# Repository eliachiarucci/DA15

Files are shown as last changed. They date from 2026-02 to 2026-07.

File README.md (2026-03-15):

# DA15 - USB Audio DAC + Amplifier

The goal of this project was to create a minimal amplifier for desktop use, using only a single USB-C cable for both data and power.
The amp outputs a max of 4.4W into 4Ω per channel, which is often enough for a good listening experience in a small room with moderately sensitive speakers.
I personally keep the volume at 30% most of the time.

The amp is also quite portable, and can be easily powered with a phone through a USB-C cable.

## Main components:

- **MCU**: STM32H503
- **DAC**: PCM5102A
- **AMP**: PAM8965

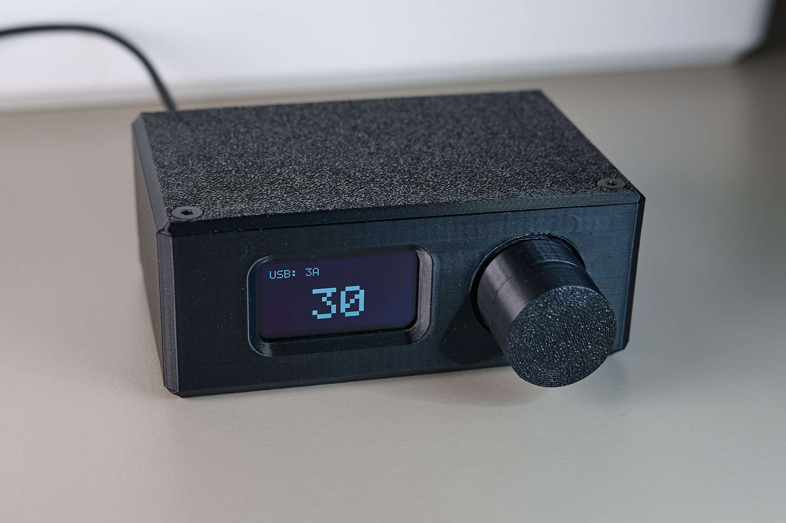
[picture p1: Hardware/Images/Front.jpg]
DA15 Front

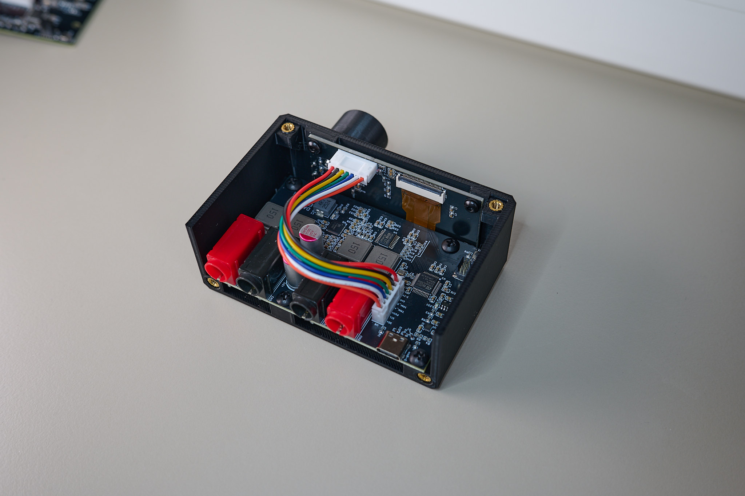
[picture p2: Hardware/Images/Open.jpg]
DA15 Top

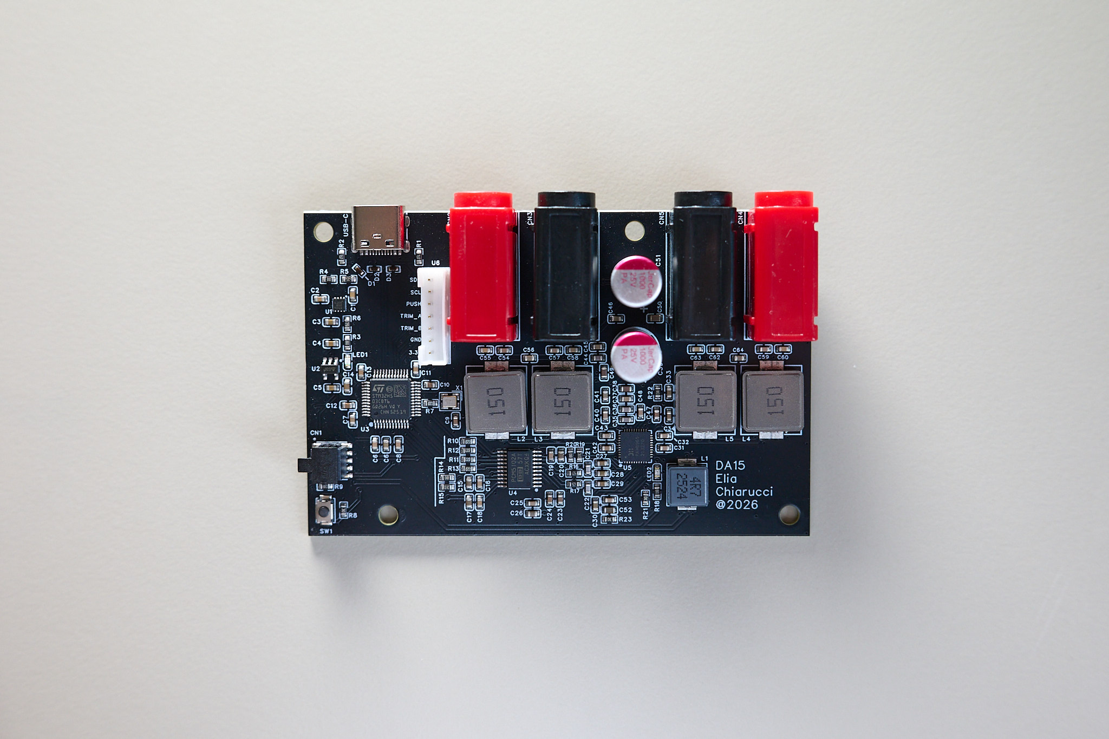
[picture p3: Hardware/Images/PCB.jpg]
DA15 PCB


For additional pictures, see [Hardware/Images](Hardware/Images/).

## Features

- **Single USB-C cable**: for both power and audio (USB Audio Class 1, 24-bit/48kHz).
- **Power** - 2 x 4.4W into 4Ω and 2 x 2.2W into 8Ω speakers (@ 0.035% THD). Can be set at max volume without losing quality.
- **USB Audio Class 1** - 24-bit/48kHz stereo with dedicated 24.576mhz audio crystal.
- **EQ** - Basic 2 bass and treble EQ or advanced EQ profiles via the [EQOS app](https://github.com/eliachiarucci/EQOS).
- **USB-C power detection** - adapts output level based on CC line voltage (500mA / 1.5A / 3A).
- **OLED UI** - SH1106 128x64 display with rotary encoder navigation.
- **DFU firmware update** - update over USB.
- **Persistent user settings** - stored in flash with wear leveling.
- **Low power consumption** - 0.5W in standby.

## Building

**Requirements:** CMake 3.22+, Ninja, ARM GCC toolchain

The [STM32 VS Code Extension](https://marketplace.visualstudio.com/items?itemName=stmicroelectronics.stm32-vscode-extension) is recommended for development.

```bash
cmake --preset Release
cmake --build build/Release
```

Or clicking the "Build" button on the bottom of VSCode.

## Debugging

There are 2 debugging profiles (in the Run and Debug tab):
**STM32Cube: STM32 Launch ST-Link GDB Server**
This is the profile created by the STM32 Extension, it will use ST-Link to flash the board.

**Debug with OpenOCD**
This profile will use OpenOCD to flash the board, and will also spawn an RTT terminal with logging directly in VSCode.

## Flashing

> **Note:** Upstream OpenOCD does not support the STM32H5 family. You need the [ST fork of OpenOCD](https://github.com/STMicroelectronics/OpenOCD) for debugging and flashing via ST-Link.
> See below for [macOS install instructions](#installing-st-openocd-for-stm32h5-support-macos).

**With ST-Link:**
```bash
openocd -f interface/stlink.cfg -f target/stm32h5x.cfg \
  -c "program build/Release/DA15.elf verify reset exit"
```

**Over USB (DFU):**
Enter DFU mode from the device menu or run `dfu-util --detach`, then:
```bash
dfu-util -a 0 -s 0x08000000:leave -D build/Release/DA15.bin
```

STM32CubeProgrammer can also be used for both ST-Link and USB DFU flashing.

## Project Structure

```
App/           Application firmware
├── Inc/       Headers
└── Src/       Implementation (audio pipeline, EQ, display, USB, settings)
Core/          STM32CubeMX generated HAL init code
Drivers/       STM32H5xx HAL library
Lib/           TinyUSB (USB stack), SEGGER RTT (debug)
```

## Installing ST OpenOCD for STM32H5 support (macOS)

```bash
# Install dependencies (if not already installed)
brew install automake autoconf libtool pkg-config libusb texinfo

# Unlink upstream OpenOCD if installed
brew unlink open-ocd 2>/dev/null

# Clone and build
git clone https://github.com/STMicroelectronics/OpenOCD.git
cd /tmp/st-openocd
./bootstrap
./configure --enable-stlink CFLAGS="-Wno-gnu-folding-constant"
make -j$(sysctl -n hw.ncpu)

# Install
sudo mkdir -p /opt/homebrew/bin /opt/homebrew/share/openocd/scripts
sudo cp src/openocd /opt/homebrew/bin/openocd
sudo cp -r tcl/* /opt/homebrew/share/openocd/scripts/

## Dependencies

| Library | License | Purpose |
|---------|---------|---------|
| [TinyUSB](https://github.com/hathach/tinyusb) | MIT | USB Audio Class 1 stack |
| [STM32H5 HAL](https://github.com/STMicroelectronics/stm32h5xx-hal-driver) | BSD-3-Clause | Hardware abstraction |
| [SEGGER RTT](https://www.segger.com/products/debug-probes/j-link/technology/about-real-time-transfer/) | BSD-1-Clause | Debug output (optional) |

## Licenses

The software of this project is licensed under the [GPL-3.0-only](LICENSE).

All the hardware files are licensed under the [CERN-OHL-S-2.0](Hardware/LICENSE).

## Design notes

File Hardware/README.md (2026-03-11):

# Hardware files for DA15.

This project was made using EasyEDA Pro (free software).

The screen and encoder PCB are part of another project that will be soon published in another repo.
However, any SH1106 screen and encoder can be used, as long as their PCB thickness is 1.6mm.

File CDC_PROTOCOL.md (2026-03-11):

# DA15 USB CDC Protocol — External App Integration Guide

## Connection

The DA15 enumerates as a USB composite device with three interfaces:
- **Audio** (UAC1 stereo speaker, 48kHz/24-bit)
- **DFU Runtime** (firmware update trigger)
- **CDC** (virtual serial port for EQ profile management)

The CDC interface has string descriptor **"DA15 EQ Config"**. Use this to identify the correct serial port.

**USB identifiers:** VID `0x1209`, PID `0xDA15`

No baud rate configuration is needed (it's USB CDC, not a real UART), but most serial libraries require one — any value works (e.g. 115200).

## Binary Frame Protocol

All communication is request/response. The host (app) sends a request, the device always replies.

### Request frame
```
[CMD:1] [LEN:2 LE] [PAYLOAD:LEN bytes] [CRC8:1]
```

### Response frame
```
[CMD|0x80:1] [LEN:2 LE] [STATUS:1] [PAYLOAD:LEN-1 bytes] [CRC8:1]
```

- **CMD**: Command byte. Response echoes it with bit 7 set (`CMD | 0x80`).
- **LEN**: Little-endian uint16. In requests, this is the payload size. In responses, this is `1 + payload_size` (the status byte counts toward the length).
- **CRC8**: Polynomial `0x07` (SMBus), initial value `0x00`. Computed over everything before the CRC byte (header + payload, or header + status + payload).

### CRC8 Implementation

```javascript
function crc8(data) {
  let crc = 0x00;
  for (const byte of data) {
    crc ^= byte;
    for (let bit = 0; bit < 8; bit++) {
      if (crc & 0x80) crc = ((crc << 1) ^ 0x07) & 0xFF;
      else crc = (crc << 1) & 0xFF;
    }
  }
  return crc;
}
```

### Status Codes

| Value | Name | Meaning |
|---|---|---|
| `0x00` | OK | Success |
| `0x01` | ERR_INVALID_CMD | Unknown command byte |
| `0x02` | ERR_INVALID_PARAM | Bad ID, wrong payload size, etc. |
| `0x03` | ERR_FLASH | Flash erase/write failed |

## Commands

### 0x01 — GET_DEVICE_INFO

**Request payload:** (none, LEN=0)

**Response payload (9 bytes):**
| Offset | Type | Field |
|---|---|---|
| 0 | uint8 | hw_model (1=DA15) |
| 1 | uint8 | hw_version_major |
| 2 | uint8 | hw_version_minor |
| 3 | uint8 | fw_version_major |
| 4 | uint8 | fw_version_minor |
| 5 | uint8 | fw_version_patch |
| 6 | uint8 | max_profiles (10) |
| 7 | uint8 | max_filters_per_profile (10) |
| 8 | uint8 | active_profile_id (0-9, or 0xFF=OFF) |

**hw_model values:**
| Value | Model |
|---|---|
| 1 | DA15 |
| 2 | HA1 |

### 0x02 — GET_PROFILE_LIST

**Request payload:** (none, LEN=0)

**Response payload (variable):**
| Offset | Type | Field |
|---|---|---|
| 0 | uint8 | count (number of stored profiles) |
| 1+ | repeated | For each profile: `[id:1] [name:16]` |

Each entry is 17 bytes: 1 byte slot ID (0-9) + 16 bytes null-terminated name. Only non-empty slots are included.

### 0x03 — GET_ACTIVE

**Request payload:** (none, LEN=0)

**Response payload (1 byte):** `[active_profile_id:1]` (0-9 for a profile, `0xFF` for OFF).

### 0x04 — GET_PROFILE

**Request payload (1 byte):** `[profile_id:1]`

**Response payload (380 bytes):** Raw `eq_profile_t` struct bytes (see data structures below).

Returns `ERR_INVALID_PARAM` if the slot is empty or ID >= 10.

### 0x05 — SET_PROFILE

**Request payload (381 bytes):** `[profile_id:1] [eq_profile_t:380]`

Writes a profile to the specified slot **in RAM only**. Call `SAVE_TO_FLASH` afterward to persist. Returns `ERR_INVALID_PARAM` if ID >= 10.

### 0x06 — DELETE_PROFILE

**Request payload (1 byte):** `[profile_id:1]`

Clears the profile slot **in RAM only**. Call `SAVE_TO_FLASH` to persist. If the deleted profile was active, the device switches to OFF. Returns `ERR_INVALID_PARAM` if ID >= 10.

### 0x07 — SET_ACTIVE

**Request payload (1 byte):** `[profile_id:1]` (0-9 for a profile, `0xFF` for OFF)

Takes effect immediately — the device switches EQ processing to the selected profile (or back to legacy bass/treble if OFF). The active profile is also persisted in the device's settings sector automatically.

### 0x08 — SAVE_TO_FLASH

**Request payload:** (none, LEN=0)

Erases the profile flash sector and writes all current profiles from RAM. Returns `ERR_FLASH` if the operation fails.

### 0x80 — GET_MANUFACTURER

**Request payload:** (none, LEN=0)

**Response payload (variable):** Current manufacturer string as raw ASCII (no null terminator).

### 0x81 — GET_PRODUCT

**Request payload:** (none, LEN=0)

**Response payload (variable):** Current product string as raw ASCII (no null terminator).

### 0x82 — GET_AUDIO_ITF

**Request payload:** (none, LEN=0)

**Response payload (variable):** Current audio interface string as raw ASCII (no null terminator).

### 0x85 — SET_MANUFACTURER

**Request payload (1–32 bytes):** Raw ASCII string (no null terminator required).

Overrides the USB manufacturer string descriptor **in RAM only**. Takes effect on the next descriptor request from the host (requires re-enumeration to be visible to the OS). Call `REBOOT` to persist all string changes to flash. Returns `ERR_INVALID_PARAM` if the payload is empty or longer than 32 bytes.

### 0x86 — SET_PRODUCT

**Request payload (1–32 bytes):** Raw ASCII string (no null terminator required).

Overrides the USB product string descriptor **in RAM only**. Same re-enumeration caveat as `SET_MANUFACTURER`. Call `REBOOT` to persist all string changes to flash. Returns `ERR_INVALID_PARAM` if the payload is empty or longer than 32 bytes.

### 0x87 — SET_AUDIO_ITF

**Request payload (1–32 bytes):** Raw ASCII string (no null terminator required).

Overrides the USB audio interface string descriptor **in RAM only**. Same re-enumeration caveat as `SET_MANUFACTURER`. Call `REBOOT` to persist all string changes to flash. Returns `ERR_INVALID_PARAM` if the payload is empty or longer than 32 bytes.

### 0x90 — ENTER_DFU

**Request payload:** (none, LEN=0)

Sends an OK response, then reboots the device into the STM32 system bootloader (DFU mode). The device re-enumerates as a DFU device for firmware flashing via `dfu-util`.

### 0x91 — GET_DFU_SERIAL

**Request payload:** (none, LEN=0)

**Response payload (12 bytes):** The DFU bootloader serial as 12 uppercase ASCII hex characters, derived from the 96-bit UID: 8 hex digits of `(UID0 + UID2)` followed by 4 hex digits of `(UID1 >> 16)`. Can be passed to `dfu-util -S <serial>` to target a specific device.

### 0x92 — REBOOT

**Request payload:** (none, LEN=0)

Persists any pending USB string descriptor changes (manufacturer, product, audio interface) to flash, then sends an OK response and performs a clean system reset via `NVIC_SystemReset()`. The device re-enumerates normally. Returns `ERR_FLASH` if the flash write fails (no reboot occurs).

### 0x93 — GET_DAC

**Request payload:** (none, LEN=0)

**Response payload (1 byte):** `0x00` = DAC muted (off), `0x01` = DAC unmuted (on).

### 0x94 — GET_AMP

**Request payload:** (none, LEN=0)

**Response payload (1 byte):** `0x00` = amplifier disabled (off), `0x01` = amplifier enabled (on).

### 0x95 — SET_DAC

**Request payload (1 byte):** `[enable:1]` — `0x00` = off (mute DAC), `0x01` = on (unmute DAC).

Directly controls the DAC mute GPIO. Returns `ERR_INVALID_PARAM` if the value is not 0 or 1.

### 0x96 — SET_AMP

**Request payload (1 byte):** `[enable:1]` — `0x00` = off (disable amplifier), `0x01` = on (enable amplifier).

Directly controls the amplifier enable GPIO. Returns `ERR_INVALID_PARAM` if the value is not 0 or 1.

## Data Structures (Binary Layout)

### eq_filter_t — 36 bytes

All floats are IEEE 754 single-precision, **little-endian** (ARM native byte order).

| Offset | Size | Type | Field | Description |
|---|---|---|---|---|
| 0 | 4 | float | b0 | Biquad coefficient |
| 4 | 4 | float | b1 | Biquad coefficient |
| 8 | 4 | float | b2 | Biquad coefficient |
| 12 | 4 | float | a1 | Biquad coefficient |
| 16 | 4 | float | a2 | Biquad coefficient |
| 20 | 4 | float | freq | Center/corner frequency (Hz) |
| 24 | 4 | float | gain | Gain in dB |
| 28 | 4 | float | q | Q factor |
| 32 | 1 | uint8 | type | Filter type (see below) |
| 33 | 1 | uint8 | enabled | 0=bypass, 1=active |
| 34 | 2 | — | padding | Set to 0x00 |

**Filter types:**
| Value | Type |
|---|---|
| 0 | OFF (filter slot unused) |
| 1 | Bell (peaking EQ) |
| 2 | Low Shelf |
| 3 | High Shelf |
| 4 | Low Pass |
| 5 | High Pass |

### eq_profile_t — 380 bytes

| Offset | Size | Type | Field | Description |
|---|---|---|---|---|
| 0 | 16 | char[16] | name | Null-terminated UTF-8 string (max 15 chars + null) |
| 16 | 1 | uint8 | filter_count | Number of active filters (0-10) |
| 17 | 3 | — | padding | Set to 0x00 |
| 20 | 360 | eq_filter_t[10] | filters | Array of 10 filter slots |

Filters beyond `filter_count` are ignored by the device but should be zeroed.

## Biquad Coefficient Computation

The values must pre-compute biquad coefficients. The device uses **Direct Form II Transposed** processing:

```
y[n] = b0*x[n] + s1
s1   = b1*x[n] - a1*y[n] + s2
s2   = b2*x[n] - a2*y[n]
```

Coefficients must be **normalized** (a0 = 1, divide all by a0). The `a1` and `a2` values stored are the standard denominator coefficients — the firmware applies them with a **minus sign** as shown above.

Use the standard Audio EQ Cookbook formulas (Robert Bristow-Johnson). Sample rate is always **48000 Hz**.

## Typical Workflow

```
1. Open CDC serial port (identify by VID/PID or "DA15 EQ Config" descriptor)
2. GET_DEVICE_INFO → check firmware version, get current state
3. GET_PROFILE_LIST → display stored profiles
4. User creates/edits a profile in the UI
5. SET_PROFILE(id, data) → upload to device RAM
6. SET_ACTIVE(id) → switch to the new profile (immediate audio effect)
7. SAVE_TO_FLASH → persist all profiles
```

For bulk operations (uploading multiple profiles), send SET_PROFILE for each, then a single SAVE_TO_FLASH at the end.

## Example: Sending GET_DEVICE_INFO

```javascript
// Build request frame
const cmd = 0x01;
const len = 0; // no payload
const frame = Buffer.from([cmd, len & 0xFF, (len >> 8) & 0xFF]);
const crcByte = crc8(frame);
const packet = Buffer.concat([frame, Buffer.from([crcByte])]);
// packet = [0x01, 0x00, 0x00, 0x79]

// Send over serial port, then read response:
// [0x81, 0x0A, 0x00, 0x00, 0x01, 0x01, 0x00, 0x01, 0x00, 0x00, 0x0A, 0x0A, 0xFF, <crc>]
//  ^CMD|0x80   ^LEN=10      ^OK  ^hw1  ^v1.0       ^fw1.0.0          ^10   ^10   ^OFF
```

## Example: Uploading a Profile

```javascript
// Build a profile with one bell filter at 1kHz, +3dB, Q=1.4
const name = Buffer.alloc(16); // null-terminated
Buffer.from('My Profile').copy(name);

const filter = Buffer.alloc(36);
// Write biquad coefficients (pre-computed for 1kHz bell, +3dB, Q=1.4, fs=48000)
filter.writeFloatLE(1.0015, 0);   // b0
filter.writeFloatLE(-1.8955, 4);  // b1
filter.writeFloatLE(0.8985, 8);   // b2
filter.writeFloatLE(-1.8955, 12); // a1 (note: firmware negates these)
filter.writeFloatLE(0.9000, 16);  // a2
filter.writeFloatLE(1000.0, 20);  // freq
filter.writeFloatLE(3.0, 24);     // gain
filter.writeFloatLE(1.4, 28);     // q
filter[32] = 1;                   // type = FILTER_BELL
filter[33] = 1;                   // enabled

// Build eq_profile_t (380 bytes)
const profile = Buffer.alloc(380);
name.copy(profile, 0);            // name at offset 0
profile[16] = 1;                  // filter_count = 1
// padding at 17-19 is already 0
filter.copy(profile, 20);         // first filter at offset 20
// remaining 9 filter slots are already zeroed

// Build SET_PROFILE request: [cmd] [len_lo] [len_hi] [id] [profile...] [crc]
const id = 0; // slot 0
const payload = Buffer.concat([Buffer.from([id]), profile]); // 381 bytes
const header = Buffer.from([0x05, payload.length & 0xFF, (payload.length >> 8) & 0xFF]);
const fullFrame = Buffer.concat([header, payload]);
const crc = crc8(fullFrame);
const packet = Buffer.concat([fullFrame, Buffer.from([crc])]);

// Send packet, expect response: [0x85, 0x01, 0x00, 0x00, <crc>]
//                                 ^CMD   ^LEN=1     ^OK

// Then persist:
// SAVE_TO_FLASH: [0x08, 0x00, 0x00, <crc>]
```

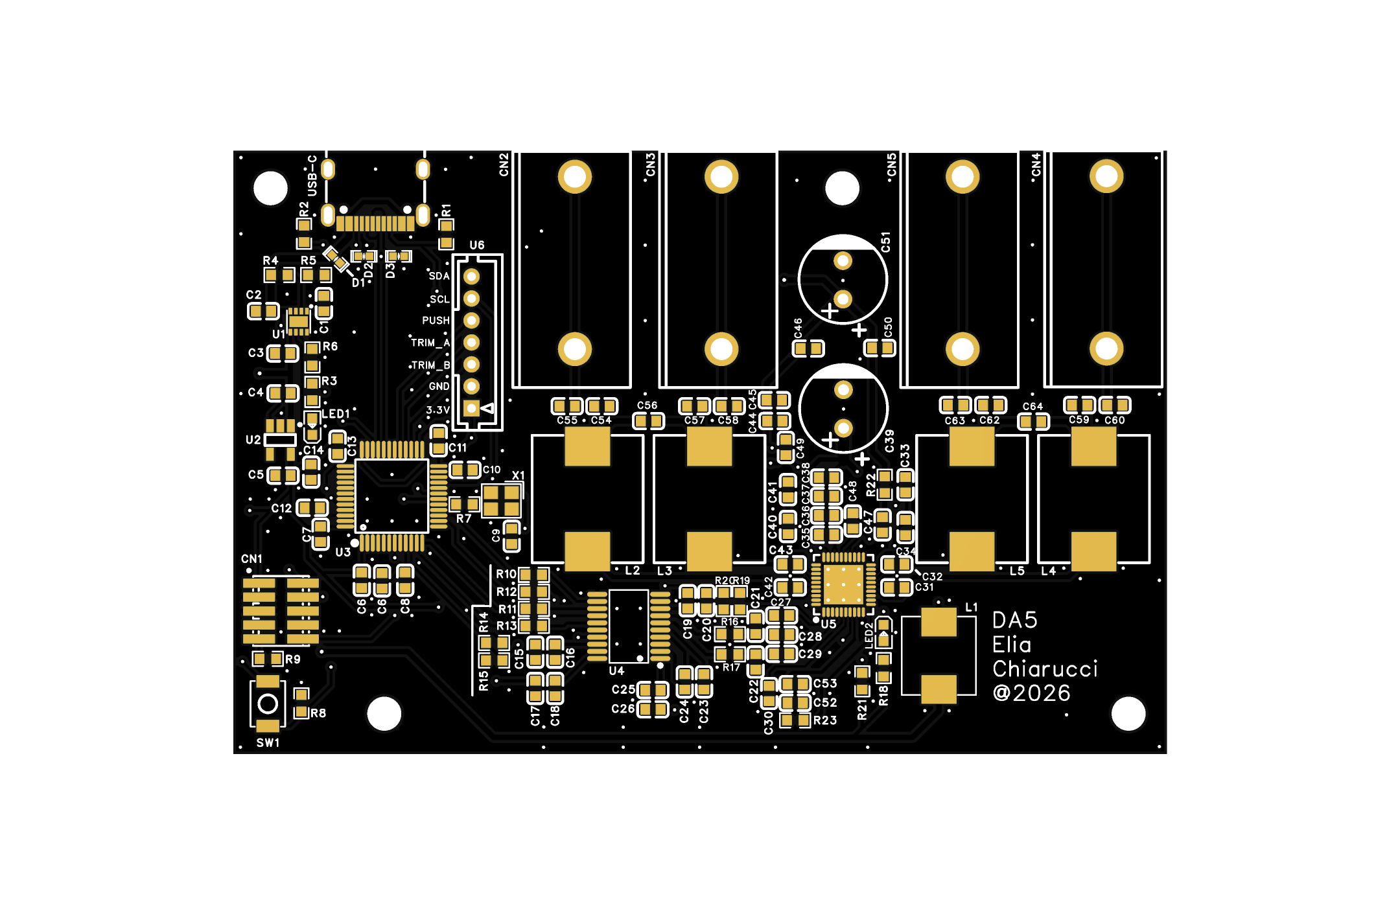
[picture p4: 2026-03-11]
Hardware/Images/2D_Render.png

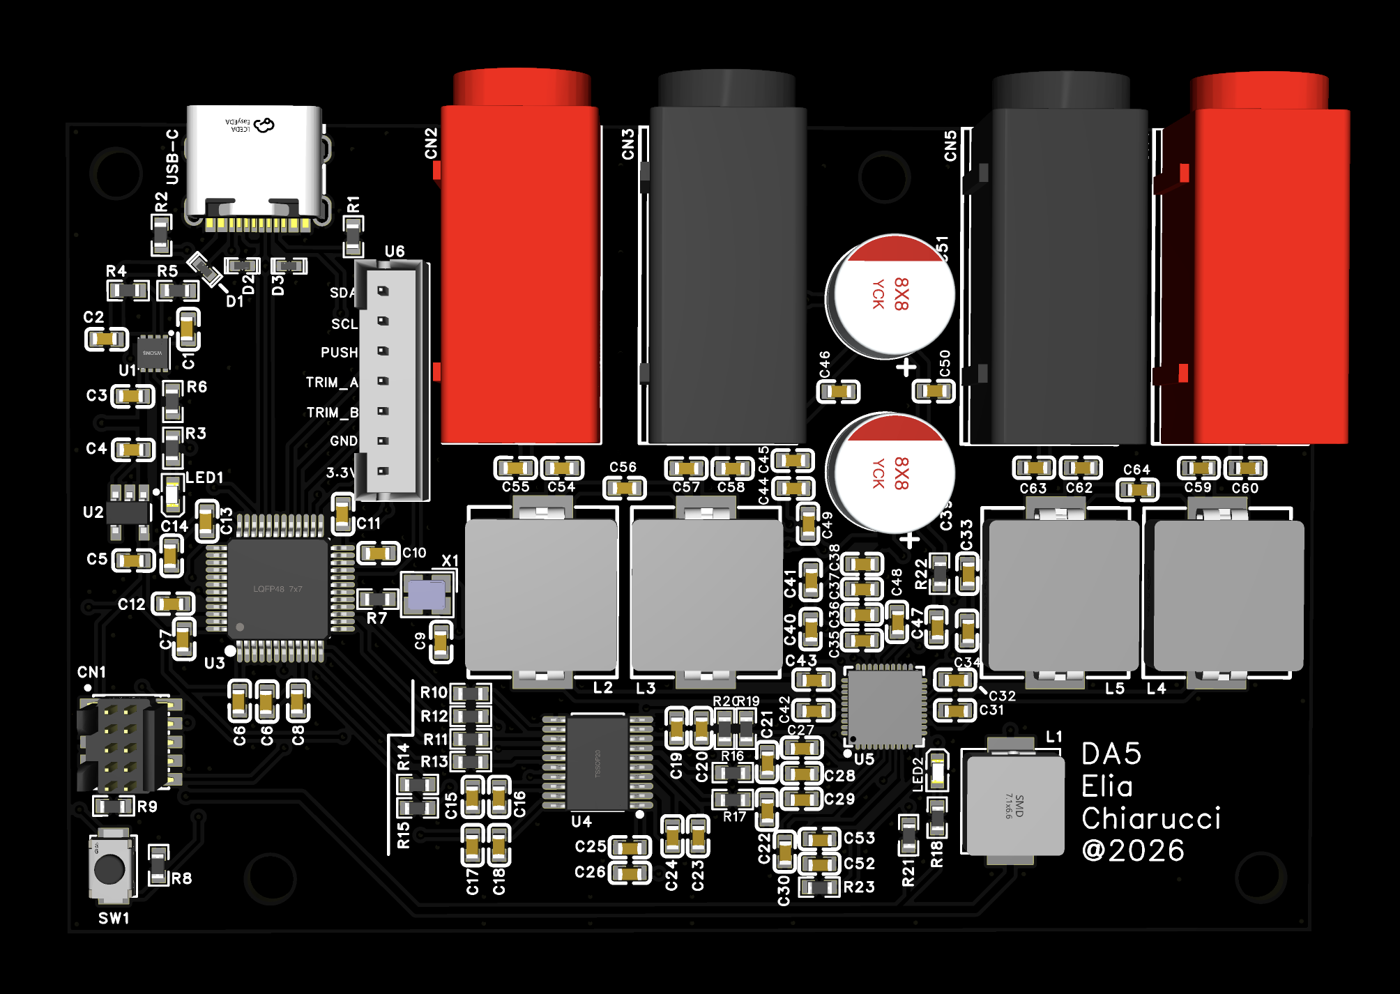
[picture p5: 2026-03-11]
Hardware/Images/3D_Render.png

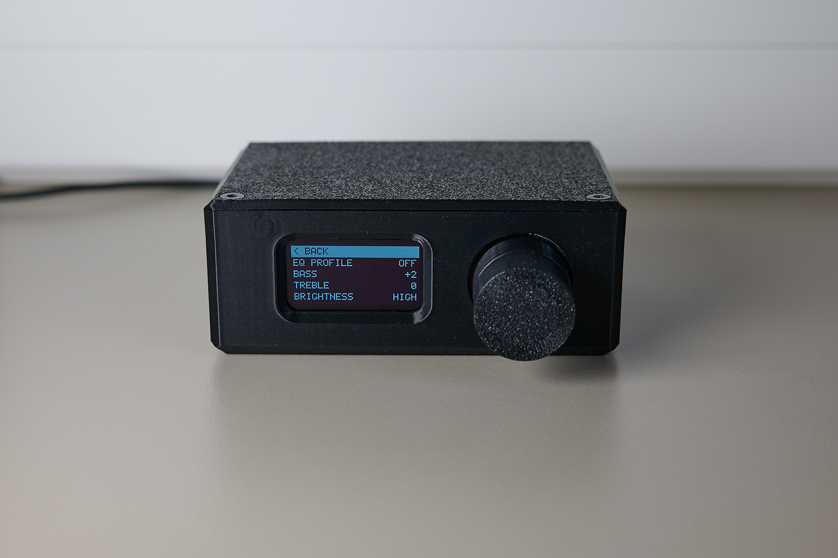
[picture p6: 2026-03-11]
Hardware/Images/Menu.jpg

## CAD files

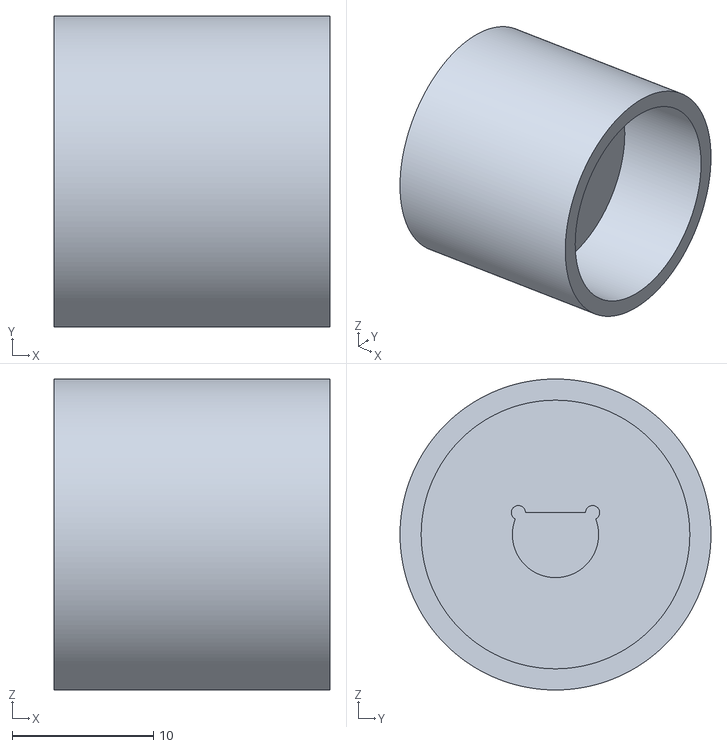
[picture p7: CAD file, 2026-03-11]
Hardware/Case/Knob.stl
19.5 x 22.0 x 22.0

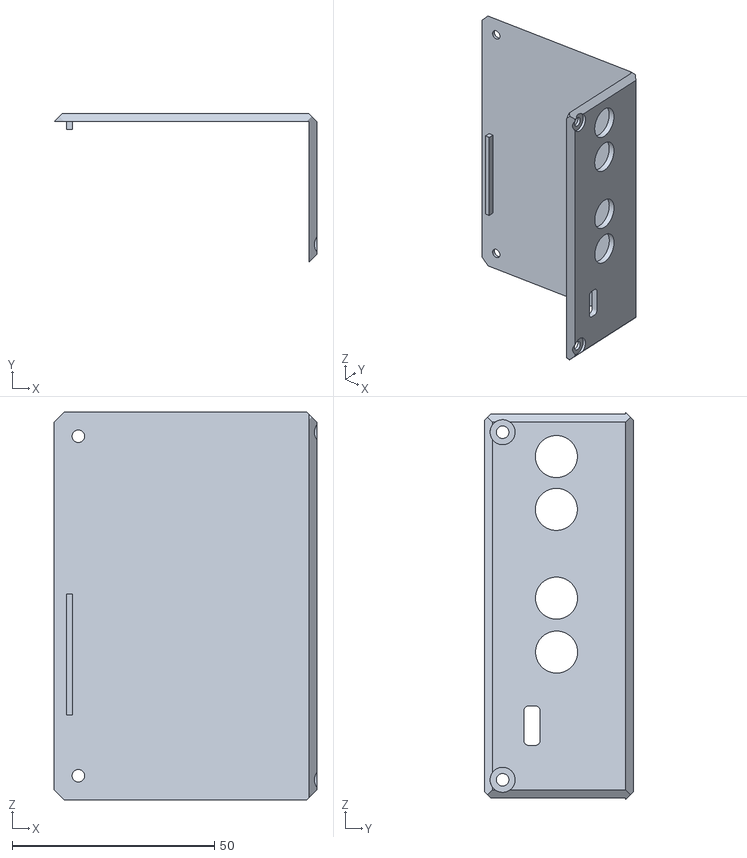
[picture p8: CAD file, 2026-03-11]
Hardware/Case/Top.stl
65.0 x 36.9 x 96.0

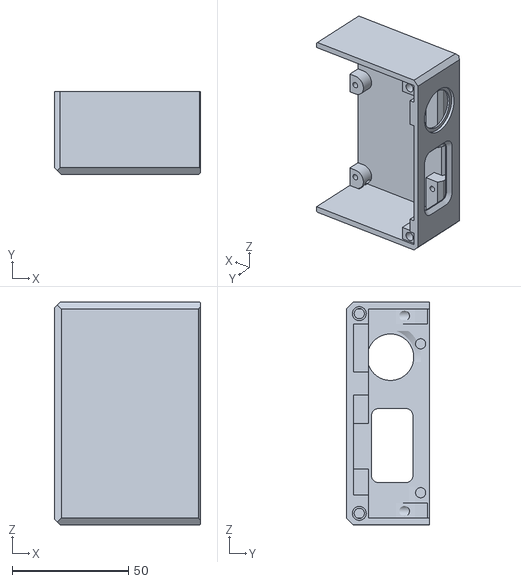
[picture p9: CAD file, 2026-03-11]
Hardware/Case/Base.stl
63.0 x 35.9 x 96.0

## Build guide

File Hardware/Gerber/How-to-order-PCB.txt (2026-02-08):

How to Order PCB

Please refer to:
https://prodocs.easyeda.com/en/pcb/order-order-pcb/index.html

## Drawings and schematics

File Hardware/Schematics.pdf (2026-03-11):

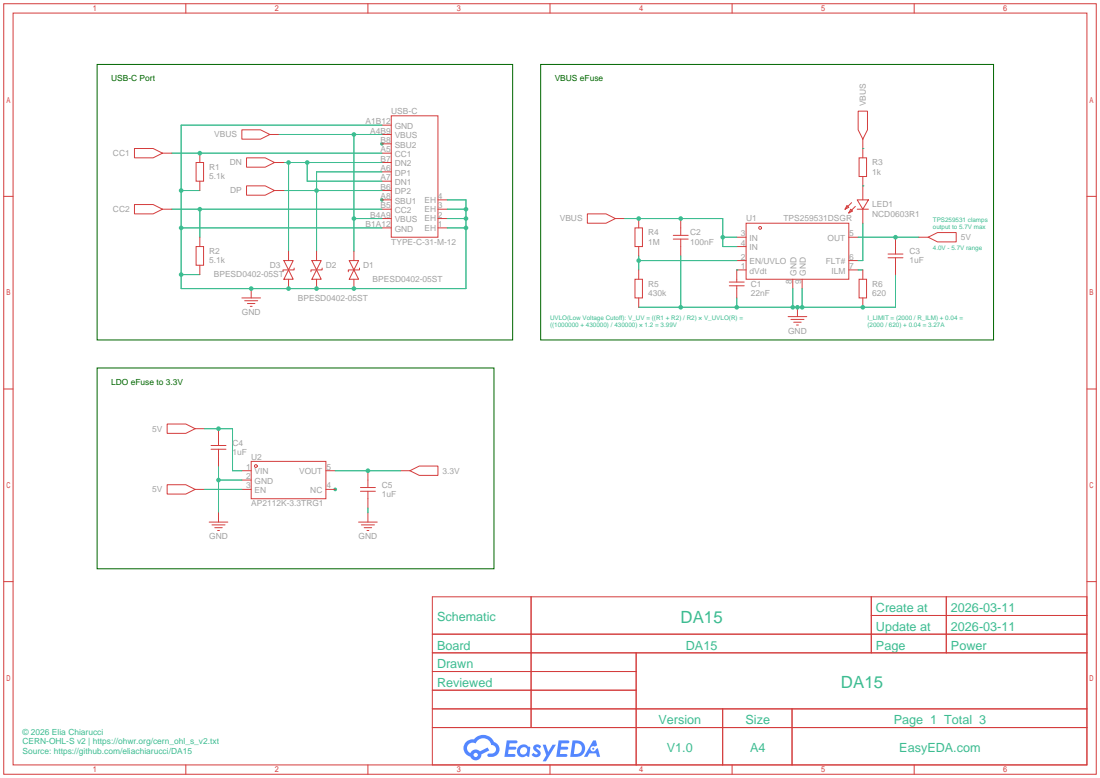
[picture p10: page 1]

UVLO(Low Voltage Cutoff): V_UV = ((R1 + R2) / R2) × V_UVLO(R) =

Schematic | DA15 | Create at | 2026-03-11

Update at | 2026-03-11

Board | DA15 | Page | Power
Drawn | | DA15
Reviewed

Version | Size | Page 1 Total 3
V1.0 | A4 | EasyEDA.com

© 2026 Elia Chiarucci
CERN-OHL-S v2 | https://ohwr.org/cern_ohl_s_v2.txt
Source: https://github.com/eliachiarucci/DA15

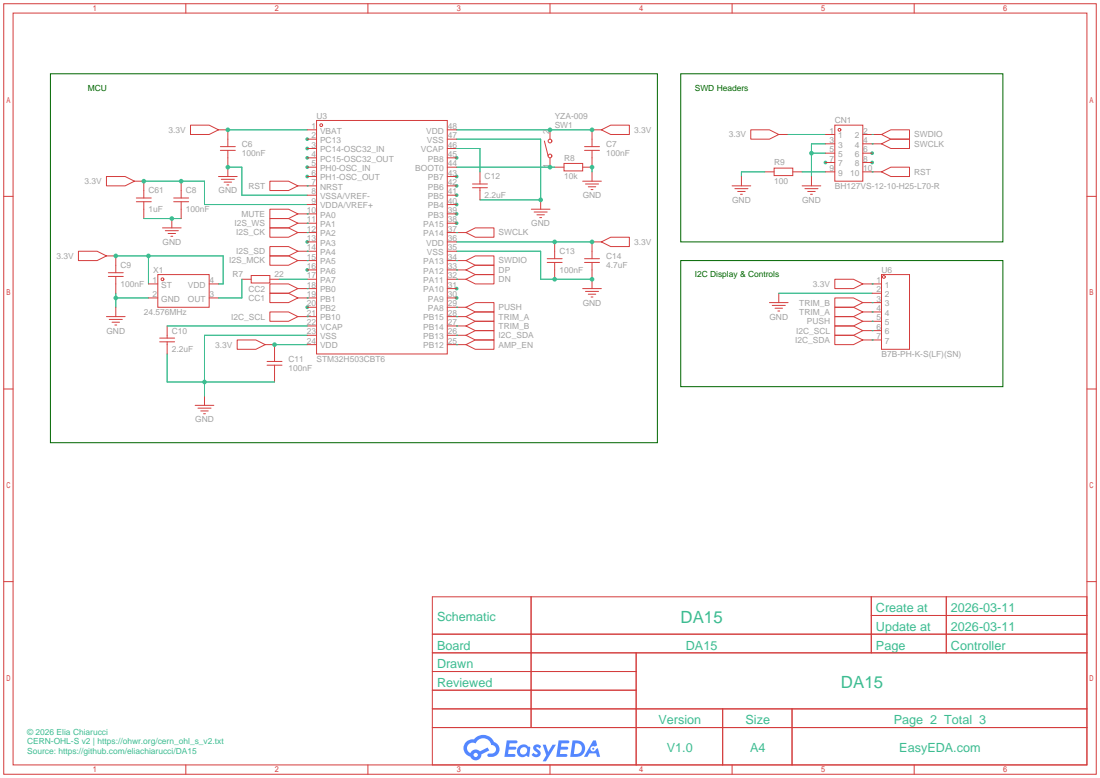
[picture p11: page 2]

Schematic | DA15 | Create at | 2026-03-11

Update at | 2026-03-11

Board | DA15 | Page | Controller
Drawn | | DA15
Reviewed

PGND 20 GAIN 21 PGND 22 PGND 23 SW 24 SW 25 BST 26 PVDD 27 PVDD 28 VBAT2 29 VBAT1 30 PGND 31 RFBN 32 ROUTN 33 RBSTN 34 RPVDD 35 RBSTP 36 ROUTP 37 RFBP 38 PGND 39 GND 40 EP 41

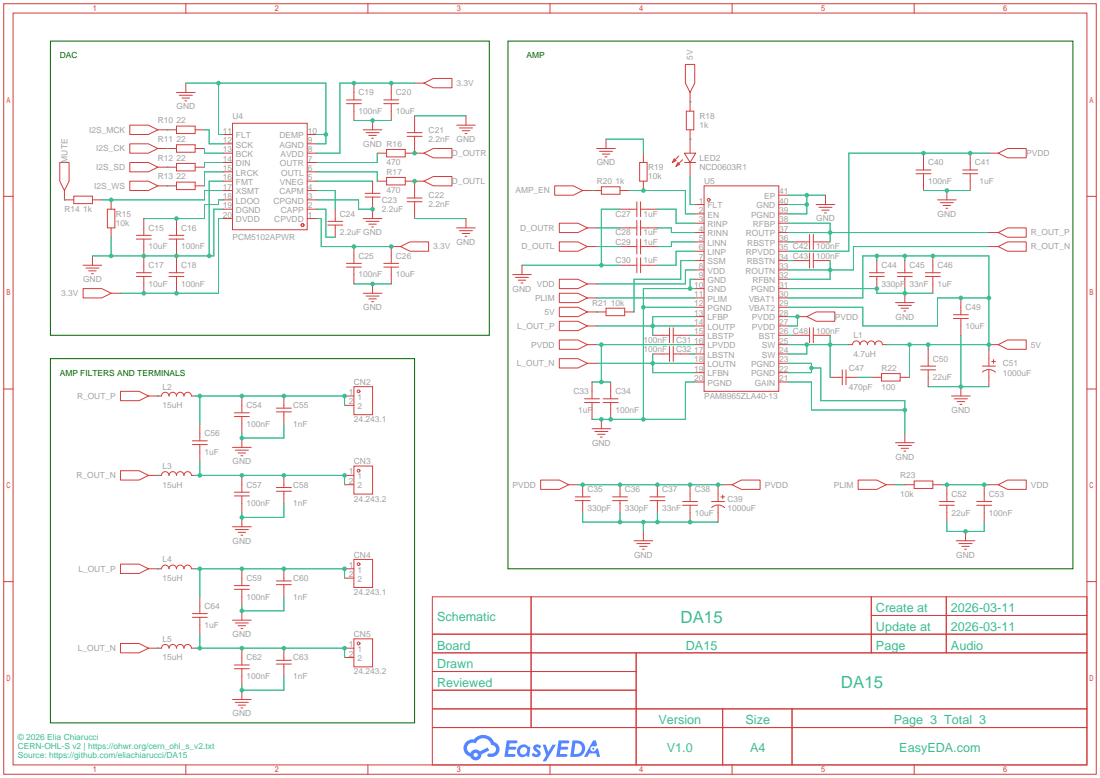
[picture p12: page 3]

AMP FILTERS AND TERMINALS

Schematic | DA15 | Create at | 2026-03-11

Update at | 2026-03-11

Board | DA15 | Page | Audio
Drawn | | DA15
Reviewed

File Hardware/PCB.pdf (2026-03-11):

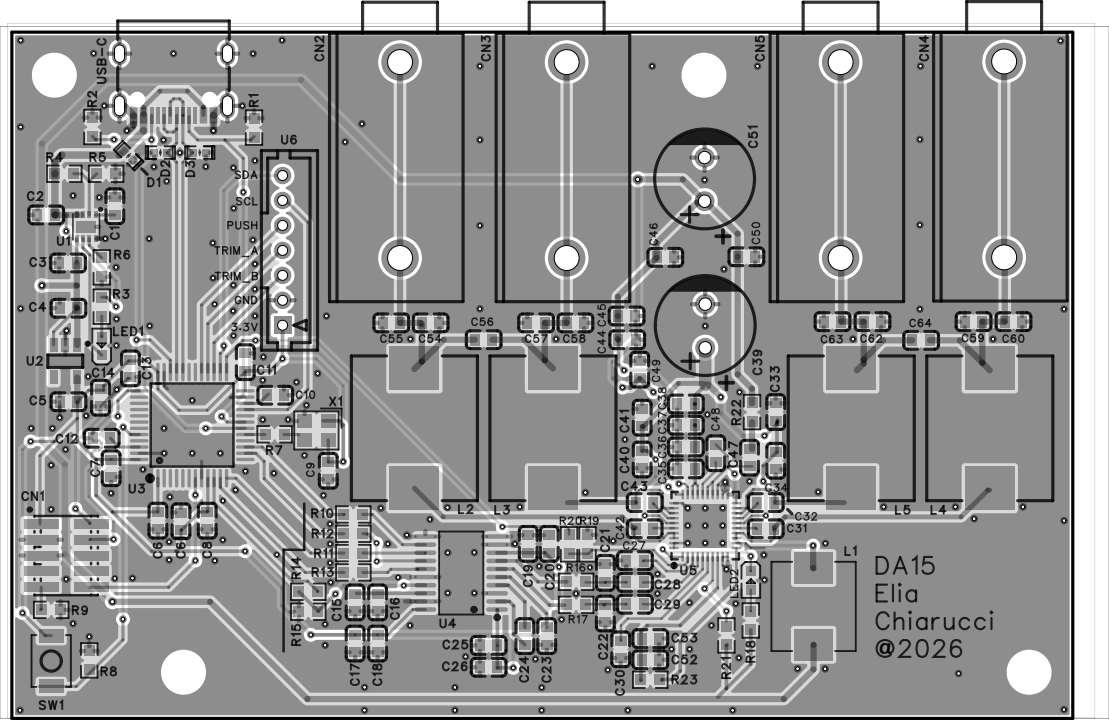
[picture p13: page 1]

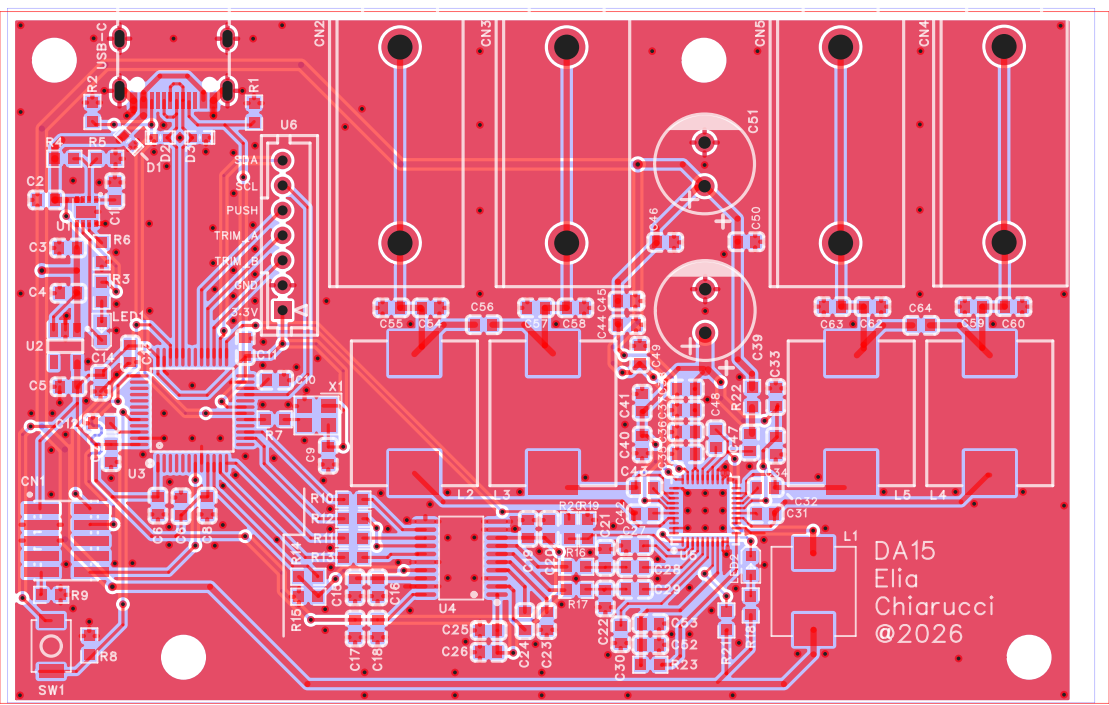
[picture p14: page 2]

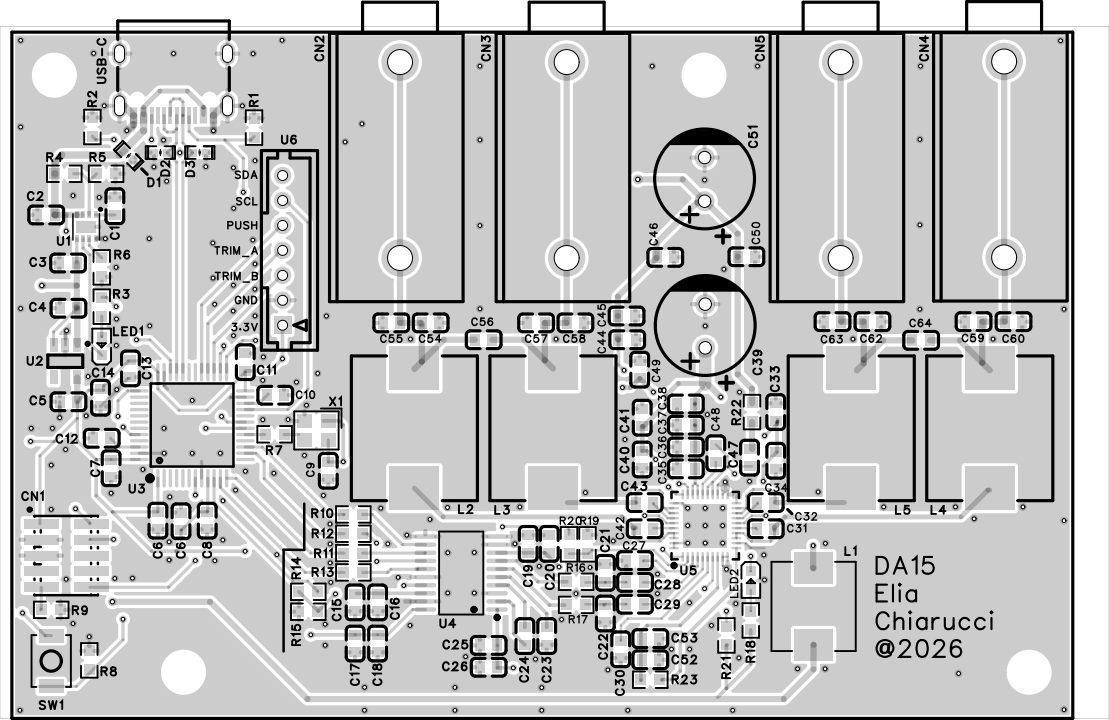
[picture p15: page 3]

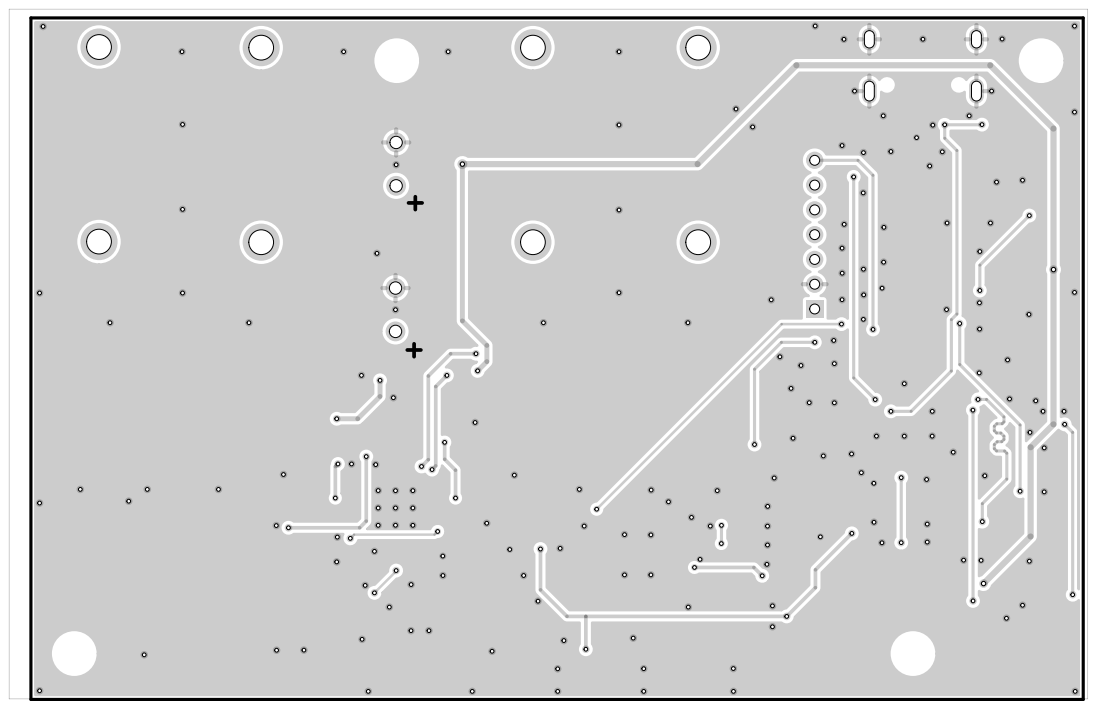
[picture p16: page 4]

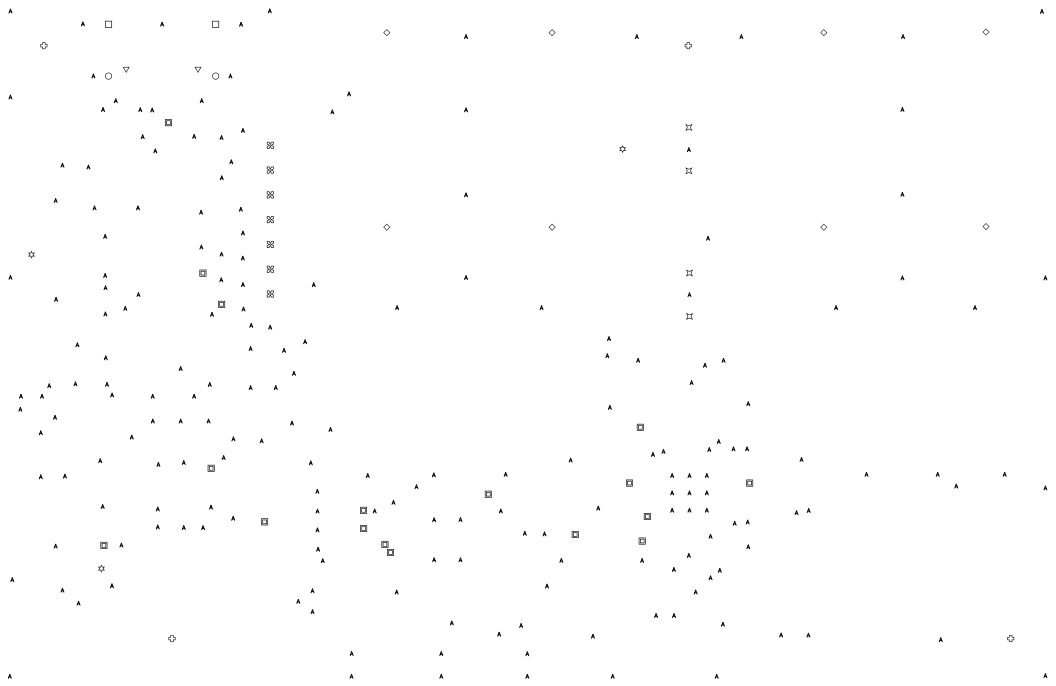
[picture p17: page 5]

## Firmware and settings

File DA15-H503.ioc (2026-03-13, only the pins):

Mcu.UserName=STM32H503CBTx
PA0.GPIO_Label=DAC_MUTE
PA0.Signal=GPIO_Output
PA1.Signal=I2S1_WS
PA11.Signal=USB_DM
PA12.Signal=USB_DP
PA2.Signal=I2S1_CK
PA4.Signal=I2S1_SDO
PA5.Signal=I2S1_MCK
PA7.Signal=AUDIOCLK
PA8.GPIO_Label=ENCODER_PUSH_I
PA8.Signal=GPIO_Input
PB0.GPIO_Label=CC2_V
PB0.Signal=ADCx_INP9
PB1.GPIO_Label=CC1_V
PB1.Signal=ADCx_INP5
PB10.Signal=I2C2_SCL
PB12.GPIO_Label=AMP_EN
PB12.Signal=GPIO_Output
PB13.Signal=I2C2_SDA
PB14.GPIO_Label=TRIM_A
PB14.Signal=GPXTI14
PB15.GPIO_Label=TRIM_B
PB15.Signal=GPXTI15

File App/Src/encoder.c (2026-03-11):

// SPDX-License-Identifier: GPL-3.0-only
// Copyright (c) 2026 Elia Chiarucci

/*
 * Rotary Encoder with Push Button
 * Quadrature decoding via full state transition table
 *
 * Uses 4x decoding (both edges of both channels A and B).
 * A state machine lookup table rejects invalid transitions caused by
 * contact bounce. Bounce between adjacent states produces alternating
 * +1/-1 that cancel in the accumulator, so no extra debounce timer
 * is needed for rotation.
 *
 * Button is polled from the main loop with software debounce and
 * long-press detection.
 *
 * Requires CubeMX config:
 * - PB15 (TRIM_A): GPIO_EXTI15, rising/falling edge, pull-up
 * - PB14 (TRIM_B): GPIO_EXTI14, rising/falling edge, pull-up
 * - PA8 (ENCODER_PUSH_I): GPIO input, pull-up
 * - NVIC: EXTI4_15 enabled
 */

#include "encoder.h"
#include "main.h"
#include "stm32h5xx_hal.h"

#define COUNTS_PER_DETENT 2
#define ENCODER_DIRECTION 1  // 1 = normal, -1 = reversed

#define BTN_DEBOUNCE_MS 50
#define LONG_PRESS_MS   1000

// Quadrature state transition table
// Index = (prev_AB << 2) | curr_AB  where AB = (A << 1) | B
// Value: +1 = CW step, -1 = CCW step, 0 = invalid/no-change (bounce rejected)
//
// CW sequence:  00 → 01 → 11 → 10 → 00
// CCW sequence: 00 → 10 → 11 → 01 → 00
static const int8_t qdec_table[16] = {
    /* prev=00 → */  0, +1, -1,  0,
    /* prev=01 → */ -1,  0,  0, +1,
    /* prev=10 → */ +1,  0,  0, -1,
    /* prev=11 → */  0, -1, +1,  0,
};

// Rotation state (ISR-updated)
static volatile int16_t encoder_accum = 0;
static volatile uint8_t prev_state = 0;  // previous AB state (2 bits)

// Button state (poll-updated)
static uint8_t btn_state = 0;
static uint8_t btn_raw_prev = 0;
static uint32_t btn_debounce_tick = 0;
static uint32_t btn_press_tick = 0;
static uint8_t btn_long_fired = 0;
static uint8_t short_press_pending = 0;
static uint8_t long_press_pending = 0;

void encoder_init(void) {
    encoder_accum = 0;
    btn_state = 0;
    btn_raw_prev = 0;
    btn_debounce_tick = 0;
    btn_press_tick = 0;
    btn_long_fired = 0;
    short_press_pending = 0;
    long_press_pending = 0;

    // Sample initial encoder state
    uint8_t a = HAL_GPIO_ReadPin(TRIM_A_GPIO_Port, TRIM_A_Pin);
    uint8_t b = HAL_GPIO_ReadPin(TRIM_B_GPIO_Port, TRIM_B_Pin);
    prev_state = (a << 1) | b;
}

void encoder_exti_callback(uint16_t GPIO_Pin) {
    if (GPIO_Pin == TRIM_A_Pin || GPIO_Pin == TRIM_B_Pin) {
        uint8_t a = HAL_GPIO_ReadPin(TRIM_A_GPIO_Port, TRIM_A_Pin);
        uint8_t b = HAL_GPIO_ReadPin(TRIM_B_GPIO_Port, TRIM_B_Pin);
        uint8_t curr_state = (a << 1) | b;

        int8_t dir = qdec_table[(prev_state << 2) | curr_state];
        encoder_accum += dir * ENCODER_DIRECTION;

        // At detent rest positions (both high or both low with pull-ups),
        // clear any fractional remainder to prevent directional bias from bounce
        if (curr_state == 0x3 || curr_state == 0x0) {
            int16_t accum = encoder_accum;
            int16_t snapped = (accum / COUNTS_PER_DETENT) * COUNTS_PER_DETENT;
            encoder_accum = snapped;
        }

        prev_state = curr_state;
    }
}

void encoder_poll(uint32_t now) {
    uint8_t btn_raw =
        (HAL_GPIO_ReadPin(ENCODER_PUSH_I_GPIO_Port, ENCODER_PUSH_I_Pin) ==
         GPIO_PIN_RESET)
            ? 1
            : 0;

    if (btn_raw != btn_raw_prev) {
        btn_debounce_tick = now;
        btn_raw_prev = btn_raw;
    }

    if ((now - btn_debounce_tick >= BTN_DEBOUNCE_MS) && btn_raw != btn_state) {
        uint8_t old_state = btn_state;
        btn_state = btn_raw;

        if (btn_state == 1 && old_state == 0) {
            btn_press_tick = now;
            btn_long_fired = 0;
        }

        if (btn_state == 0 && old_state == 1) {
            if (!btn_long_fired) {
                short_press_pending = 1;
            }
        }
    }

    if (btn_state == 1 && !btn_long_fired &&
        (now - btn_press_tick >= LONG_PRESS_MS)) {
        btn_long_fired = 1;
        long_press_pending = 1;
    }
}

int8_t encoder_get_delta(void) {
    // Brief critical section: extract whole detent steps, keep remainder
    __disable_irq();
    int16_t accum = encoder_accum;
    int8_t steps = (int8_t)(accum / COUNTS_PER_DETENT);
    encoder_accum = accum - (int16_t)steps * COUNTS_PER_DETENT;
    __enable_irq();
    return steps;
}

bool encoder_has_short_press(void) {
    if (short_press_pending) {
        short_press_pending = 0;
        return true;
    }
    return false;
}

bool encoder_has_long_press(void) {
    if (long_press_pending) {
        long_press_pending = 0;
        return true;
    }
    return false;
}

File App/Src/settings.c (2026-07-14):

// SPDX-License-Identifier: GPL-3.0-only
// Copyright (c) 2026 Elia Chiarucci

/*
 * Persistent Settings Storage
 *
 * Uses the last flash sector (8KB at 0x0801E000) for sequential record writing.
 * Each record is 16 bytes (quad-word aligned):
 *   [magic, volume, muted, bass, treble, brightness, timeout, profile, checksum, 0xFF x7]
 * Records are appended sequentially; when the sector is full it is erased.
 * On load, the last valid record is used.
 *
 * STM32H503: 8KB sectors, quad-word (128-bit / 16-byte) programming.
 *
 * ECC recovery: if power is lost during a quad-word flash write, the partially
 * programmed word will have invalid ECC. Reading it triggers an NMI. The NMI
 * handler sets settings_ecc_error, and settings_load() erases the sector and
 * falls back to defaults.
 */

#include "settings.h"
#include "SEGGER_RTT.h"
#include "stm32h5xx_hal.h"
#include <string.h>

#define SETTINGS_BANK        FLASH_BANK_2 // Bank 2 (0x08010000–0x0801FFFF)
#define SETTINGS_SECTOR      7U           // Last 8KB sector of bank 2
#define SETTINGS_PAGE_ADDR   0x0801E000U  // Bank 2, Sector 7 base address
#define SETTINGS_PAGE_SIZE   8192U        // 8KB sector
#define RECORD_SIZE          16U          // Quad-word aligned (16 bytes)
#define MAX_RECORDS          (SETTINGS_PAGE_SIZE / RECORD_SIZE)
#define RECORD_MAGIC         0xA6U
#define ERASED_BYTE          0xFFU

// Strings record: 7 × 16 bytes = 112 bytes
// Layout: [magic:1][manufacturer:32][product:32][audio_itf:32][checksum:1][pad:14]
#define STRINGS_MAGIC        0xC3U
#define STRINGS_RECORD_QUADS 7U
#define STRINGS_RECORD_SIZE  (STRINGS_RECORD_QUADS * RECORD_SIZE) // 112 bytes
#define STRINGS_CKSUM_LEN    97U  // bytes 0..96 covered by checksum

// Set by NMI handler on flash ECC double-detection error
volatile uint8_t settings_ecc_error = 0;

static uint8_t compute_checksum(const uint8_t *rec, uint8_t len) {
    uint8_t cksum = 0;
    for (uint8_t i = 0; i < len; i++)
        cksum ^= rec[i];
    return cksum;
}

static bool erase_settings_page(void) {
    HAL_FLASH_Unlock();

    FLASH_EraseInitTypeDef erase = {
        .TypeErase = FLASH_TYPEERASE_SECTORS,
        .Banks     = SETTINGS_BANK,
        .Sector    = SETTINGS_SECTOR,
        .NbSectors = 1,
    };
    uint32_t sector_error = 0;
    HAL_StatusTypeDef status = HAL_FLASHEx_Erase(&erase, &sector_error);

    HAL_FLASH_Lock();

    // Invalidate ICACHE so subsequent flash reads don't return stale data
    HAL_ICACHE_Invalidate();

    return status == HAL_OK;
}

static int find_next_free_slot(void) {
    const uint8_t *base = (const uint8_t *)SETTINGS_PAGE_ADDR;
    settings_ecc_error = 0;

    for (int i = 0; i < (int)MAX_RECORDS; i++) {
        const uint8_t *rec = base + (i * RECORD_SIZE);
        uint8_t all_erased = 1;
        for (uint8_t j = 0; j < RECORD_SIZE; j++) {
            volatile uint8_t b = rec[j]; // volatile: read may trigger NMI
            if (settings_ecc_error) {
                erase_settings_page();
                settings_ecc_error = 0;
                return 0;
            }
            if (b != ERASED_BYTE) { all_erased = 0; break; }
        }
        if (all_erased) return i;
    }
    return -1;
}

bool settings_load(settings_t *out) {
    const uint8_t *base = (const uint8_t *)SETTINGS_PAGE_ADDR;

    // Clear any pending ECC error state
    settings_ecc_error = 0;

    // Scan backwards to find last valid record
    for (int i = (int)MAX_RECORDS - 1; i >= 0; i--) {
        const uint8_t *rec = base + (i * RECORD_SIZE);
        volatile uint8_t magic = rec[0]; // volatile: read may trigger NMI on ECC error

        // If reading flash triggered an ECC error (NMI handler sets flag),
        // the sector has a partially-written quad-word from a power loss.
        // Erase it and return defaults.
        if (settings_ecc_error) {
            SEGGER_RTT_printf(0, "[settings] ECC error at record %d, erasing sector\n", i);
            erase_settings_page();
            settings_ecc_error = 0;
            return false;
        }

        if (magic != RECORD_MAGIC) continue;

        // Checksum covers bytes 0-7, stored in byte 8
        uint8_t cksum = compute_checksum(rec, 8);
        if (settings_ecc_error) {
            SEGGER_RTT_printf(0, "[settings] ECC error at record %d, erasing sector\n", i);
            erase_settings_page();
            settings_ecc_error = 0;
            return false;
        }
        if (cksum != rec[8]) continue;

        out->local_volume    = rec[1];
        out->local_muted     = rec[2];
        out->bass            = (int8_t)rec[3];
        out->treble          = (int8_t)rec[4];
        out->brightness      = rec[5];
        out->display_timeout = rec[6];
        out->active_profile  = rec[7];
        return true;
    }

    return false;
}
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

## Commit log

2026-02-07 add pcb files
    [DA15_BOTTOM.stl, DA15_KNOB.stl, DA15_TOP.stl]
2026-02-08 update pcb
2026-02-08 update schematics
2026-02-08 add gerber file
    [Drill_NPTH_Through.DRL, Drill_PTH_Through.DRL, Drill_PTH_Through_Via.DRL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]
2026-02-08 fix: timeout glitch and usb events debounce
    [app.c, display.c]
2026-02-11 update PID
2026-02-17 fix: pop issue when stopping and starting streaming fast
    [audio_output.c]
2026-02-20 feat: changed to support STM32H503 MCU
2026-03-01 feat: update CubeMX version files, add workaround for SAI1 extern clock bug
    [DA15-H503.ioc]
2026-03-01 feat: add get/set commands for manufacturer, model, dac & amp status, and reboot
    [audio_output.c]
2026-03-05 feat: add support for HA1 amp and fix pre-attenuation logic
    [audio_output.c, eq_profile.c]
2026-03-07 feat: rename profile and don't swap channels for HA1
    [audio_output.c]
2026-03-10 feat: update readme, adjust encoder rotation detection
2026-03-10 docs: add standby power consumption figure
2026-03-10 docs: update readme power figures
2026-03-11 docs: update hardware file for new version
    [Drill_NPTH_Through.DRL, Drill_PTH_Through.DRL, Drill_PTH_Through_Via.DRL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]
2026-03-11 docs: update comments and update 3d files
    [Base.stl, DA15_BOTTOM.stl, DA15_KNOB.stl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]
2026-03-11 docs: update power figure in introduction
2026-07-14 feat: audit hardening (watchdog, fault capture, DFU-safe RAM layout, tests, CI)
    * fix: reserve DFU magic RAM region above the stack
    * perf: single-multiply Q12 EQ and unity-gain bypass
    * feat: watchdog, fault management and audio/USB hardening
    * test: add host unit tests, static analysis and CI
    * revert: keep amp enabled during USB suspend
    [app.c, audio_output.c, display.c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]
